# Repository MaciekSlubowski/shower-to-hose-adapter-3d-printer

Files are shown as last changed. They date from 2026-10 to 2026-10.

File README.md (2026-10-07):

# G 1/2" to Hose Barb Adapter

A heavy-duty, 3D-printable adapter connecting a standard G 1/2" shower hose to a flexible aquarium or garden hose.
Written in OpenSCAD, this parametric model features an ergonomic cross handle (faucet knob) for easy, tool-free tightening and reinforced walls for secure clamping.

## 📷 Gallery

<p align="center">
  OpenSCAD Render
  Top View
  Side Profile
  Assembled System
</p>

* **OpenSCAD Render:** 3D visualization of the generated parametric model.
* **Top View:** Printed adapter standing vertically, showcasing the thick-walled internal bore and robust cross handle.
* **Side Profile:** Central hub, hose barb teeth, and the G 1/2" thread base.
* **Assembled System:** The adapter screwed into a metal shower hose fitting and secured to a flexible hose worm-drive clamp.

## 📏 Default Dimensions

Based on the default parameters in the OpenSCAD file, the generated adapter has the following specifications:
* **Shower Thread:** G 1/2" (BSPP)
* **Hose Barb:** Designed for a 12.5 mm (1/2") inner diameter hose
* **Internal Bore:** 7.5 mm (Ensures thick, heavy-duty walls)
* **Handle Type:** 4-spoke cross knob (26 mm hub, ~58 mm total span)

## ✨ Features

* **Fully Parametric:** Easily adjust hose diameter, thread clearance, and wall thickness directly in the OpenSCAD file to fit your specific setup.
* **Heavy-Duty Walls:** The internal bore is narrowed to create a thick, pressure-resistant structure. It will not crack or crush under the heavy tension of a metal worm-drive hose clamp.
  
## 🖨️ Recommended Print Settings

To ensure the adapter is watertight and withstands mains water pressure without delaminating, follow these guidelines:
* **Material:** PETG or PETG-CF (Carbon Fiber) works best for layer adhesion and impact resistance. Do not use TPU (too soft for threads) or standard PLA (too brittle).
* **Layer Height:** 0.12 mm - 0.16 mm. A low layer height is MANDATORY to accurately resolve the fine pitch of the G 1/2" thread.
* **Walls/Perimeters:** 3-4 walls (for watertightness and structural strength).
* **Top/Bottom Thickness:** 1.2 mm - 1.6 mm.
* **Z-Seam:** 'Aligned' or 'Sharpest Corner'. Do NOT use 'Random', as scattered seam bumps on the threads will prevent the shower gasket from sealing properly.

## ⚠️ Note on Material Shrinkage & Assembly

FDM plastics tend to shrink slightly after printing and cooling down. To compensate for this and ensure a perfect fit:
* The OpenSCAD script independently scales down the thread by 1% (`thread_scale = 0.99`) for a smooth fit into the shower hose nut.
* The script scales up the hose barb by 1% (`barb_scale = 1.01`) to guarantee a tight, watertight seal against the flexible hose.

> **Pro-Tip for Assembly:** Before sliding your hose onto the printed barb, dip the end of the hose in boiling water for 30 seconds. The heat will soften the rubber/PVC, allowing it to glide over the scaled-up teeth easily. Once it cools, it will shrink-fit tightly around the printed part. Secure it with a metal hose clamp for a permanent, leak-proof connection.

---
*This project is open-source and provided strictly for personal, educational, and non-commercial purposes. You are free to explore, modify, and learn from the codebase. If you wish to use this project for commercial purposes, please contact me. Developed and designed by Maciej Ślubowski.

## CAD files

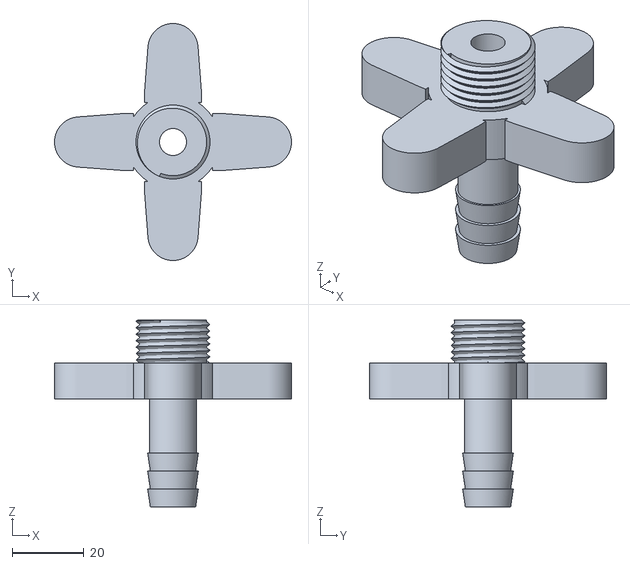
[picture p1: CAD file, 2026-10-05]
shower-to-hose-adapter-3d-printer.stl
66.0 x 66.0 x 52.0

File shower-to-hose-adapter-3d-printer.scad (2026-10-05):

/*
  Plumbing Connector: Shower Hose (G 1/2" Thread) -> Garden/Aquarium Hose
  Version: Cross handle (faucet style), custom scaling factors, and reinforced heavy-duty walls.
*/

// --- CONFIGURATION VARIABLES ---
hose_inner_diam = 12.5;     // Inner diameter of your flexible hose (mm)
thread_clearance = 0.15;    // Thread tolerance (mm) to compensate for FDM material shrinkage
$fn = 100;                  // High resolution for smooth arcs and cylinders

// --- MATERIAL SCALING FACTORS ---
thread_scale = 0.99;        // Scale down the thread by 1% for a perfect fit
barb_scale = 1.01;          // Scale up the hose barb by 1% for a tighter water seal

// --- INTERNAL PARAMETERS (Calculated) ---
// G 1/2" Thread (BSPP) - Scaled down
thread_od = (20.95 * thread_scale) - thread_clearance;
thread_pitch = 1.814 * thread_scale;
thread_length = 12;

// Cross Handle (Faucet Knob) - Replaces standard hex nut for better manual leverage
handle_hub_diam = 26;       // Diameter of the central solid hub
handle_height = 10;         // Z-height (thickness) of the handle for a comfortable grip
handle_spoke_len = 20;      // Length of the spokes extending from the hub

// Hose Barb - Scaled up
barb_length_total = 30;
barb_teeth_count = 3;
barb_tooth_height = 5;
barb_max_diam = (hose_inner_diam + 1.5) * barb_scale;
barb_min_diam = hose_inner_diam * barb_scale;
smooth_shank_len = 15;
smooth_shank_diam = (hose_inner_diam + 0.5) * barb_scale;

// Internal Bore (Through-hole)
// Wall thickening: reducing bore diameter by 5 mm creates heavy-duty, pressure-resistant walls
bore_diam = hose_inner_diam - 5; 

// --- MAIN MODULE ASSEMBLY ---
difference() {
    union() {
        // 1. G 1/2" Thread (Top Section)
        translate([0, 0, barb_length_total + handle_height])
            simple_thread(od=thread_od, pitch=thread_pitch, length=thread_length);

        // 2. Cross Handle (Middle Section)
        translate([0, 0, barb_length_total])
            cross_handle(hub_diam=handle_hub_diam, height=handle_height, spoke_length=handle_spoke_len);

        // 3. Hose Barb (Bottom Section)
            build_barb();
    }

    // 4. Continuous Internal Bore (subtracting the through-hole)
    translate([0, 0, -1])
        cylinder(h = barb_length_total + handle_height + thread_length + 2, d = bore_diam);
}

// --- HELPER MODULES ---

module cross_handle(hub_diam, height, spoke_length) {
    spoke_tip_diam = 14;   // Rounded tip diameter (ergonomic for wet hands)
    spoke_base_width = 16; // Wide spoke base to prevent snapping under torque
    
    union() {
        // Central hub
        cylinder(h=height, d=hub_diam);
        
        // 4 extending spokes (cross pattern)
        for(i=[0:90:270]) {
            rotate([0, 0, i]) {
                hull() {
                    // Base firmly merged into the central hub
                    translate([hub_diam/2 - 2, -spoke_base_width/2, 0])
                        cube([2, spoke_base_width, height]);
                    
                    // Rounded tip placed at the designated spoke length
                    translate([hub_diam/2 + spoke_length - spoke_tip_diam/2, 0, 0])
                        cylinder(h=height, d=spoke_tip_diam);
                }
            }
        }
    }
}

module build_barb() {
    // Barb teeth (stacking upwards)
    for(i = [0 : barb_teeth_count - 1]) {
        translate([0, 0, i * barb_tooth_height])
            cylinder(h=barb_tooth_height, d1=barb_min_diam, d2=barb_max_diam);
    }
    
    // Smooth shank area specifically designed for a metal hose clamp
    translate([0, 0, barb_teeth_count * barb_tooth_height])
        cylinder(h=smooth_shank_len, d=smooth_shank_diam);
}

module simple_thread(od, pitch, length) {
    r = od/2;
    // Thread profile optimized for 3D printing overhangs and structural stability
    r_core = r - (0.866 * pitch * 0.625);
    res = $fn > 0 ? $fn : 60;
    z_step = pitch/res;
    a_step = 360/res;
    num_steps = ceil((length/pitch) * res);

    intersection() {
        // Outer bounding cylinder to cut off excess thread ends flat (ensures proper gasket seal)
        cylinder(h=length, r=r, $fn=res); 
        union() {
            // Core cylinder with a slight overlap to guarantee manifold geometry
            cylinder(h=length, r=r_core + 0.05, $fn=res);
            // Spiral generation via hulling 2D profiles
            for(i=[0:num_steps-1]) {
                hull() {
                    _thread_profile(r, r_core, pitch, i*a_step, i*z_step);
                    _thread_profile(r, r_core, pitch, (i+1)*a_step, (i+1)*z_step);
                }
            }
        }
    }
}

module _thread_profile(r, r_core, pitch, a, z) {
    rotate([0, 0, a])
    translate([r_core, 0, z])
    rotate([90, 0, 0])
    // Flat 2D cross-section extruded and hulled to form the 3D spiral
    linear_extrude(0.01, center=true)
    polygon([ [-0.1, -pitch/2], [r-r_core, 0], [-0.1, pitch/2] ]);
}

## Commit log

2026-10-05 Add README for G 1/2" to Hose Barb Adapter
    Added detailed information about the G 1/2" to Hose Barb Adapter, including specifications, features, print settings, and assembly tips.
2026-10-06 Clarify assembled system description in README
    Updated the description of the assembled system to clarify the use of the worm-drive clamp.
2026-11-13 v2: Heavy-duty reinforced adapter
    - Bore reduced 7.5 -> 6.0 mm with conical lead-ins at both ends
    - Thread lengthened 12 -> 14 mm with a 2 mm stress-relief collar at the root
    - Shallower thread root and larger core overlap
    - Cross knob: hub 28 mm, height 12 mm, wider spoke roots
    - Larger barb teeth with flat crests
    - Longer, thicker clamp shank with two worm-drive retention ribs
    - Anti-snap cone between shank and knob
    - README: updated dimensions, features and changelog
2026-11-13 v2.1: Fix thread fit for printing at 100%
    v1 only fitted the shower nut after an extra 98% scale in the slicer,
    and v2's shallower root made the core (~18.79 mm) even larger than the
    nut's minor diameter (18.63 mm).
    - thread_scale 0.99 -> 0.97 (crest ~20.17 mm, same as the fitted print)
    - Explicit thread_depth = 0.98 -> printed root ~18.37 mm
    - Pitch kept at nominal 1.814 mm (no longer scaled)
    - README: updated shrinkage/fit notes
2026-11-13 Split v1 and v2 into separate files, rework README
    - v1 restored in shower-to-hose-adapter-3d-printer.scad/.stl,
    v2 moved to shower-to-hose-adapter-3d-printerv2.scad/.stl
    - README restructured to match aquarium-refill-hose-holder:
    versions table, v1/v2 dimensions, usage, key parameters,
    project structure, fit & tolerances, changelog, license badge
    - OpenSCAD renders of v2 in images/; photos marked as the v1 prototype
